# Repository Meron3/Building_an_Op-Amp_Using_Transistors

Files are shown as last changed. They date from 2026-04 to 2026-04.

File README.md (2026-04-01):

# トランジスタで作るスピーカーアンプ

トランジスタ16石で作るスピーカーアンプのkicadプロジェクトです。

kicad9.0以降で開くことができます。

トグルスイッチのフットプリントは、nosuz様のkicad-libをインポートして使用しています。
https://github.com/nosuz/kicad-lib

# 回路図

circuit

# Overview

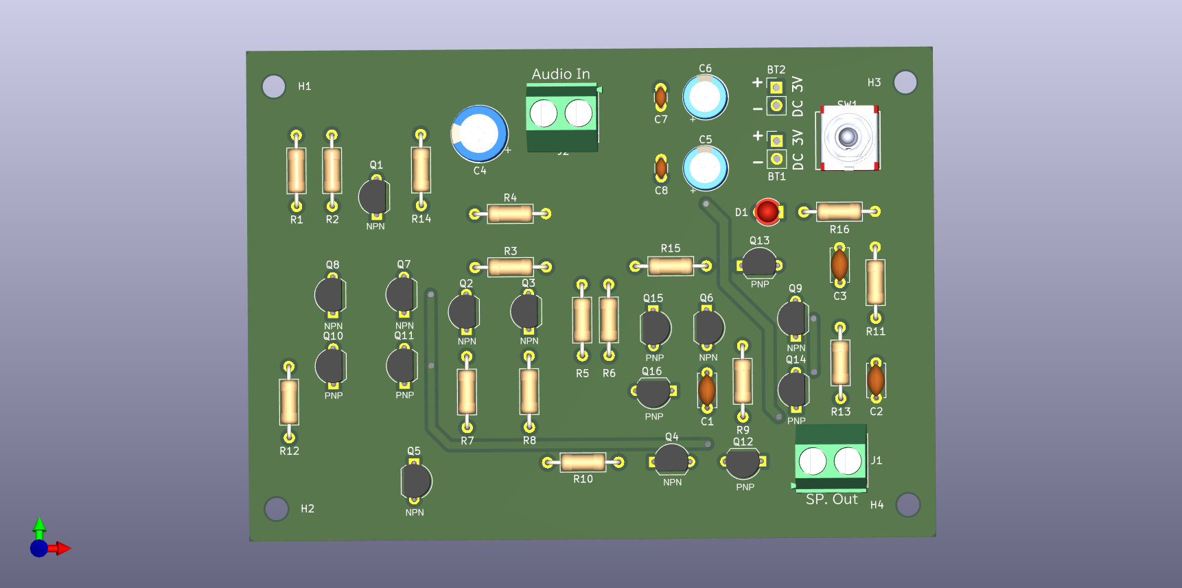
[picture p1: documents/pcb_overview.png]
overview


# Building an Op-Amp Using Transistors

This is a KiCad project for a speaker amplifier using 16 transistors.

It can be opened with KiCad 9.0 or later.

The toggle switch footprint uses KiCad-lib imported by nosuz.
https://github.com/nosuz/kicad-lib

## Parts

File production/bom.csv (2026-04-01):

Designator | Footprint | Quantity | Value | LCSC Part #
BT1, BT2 | PinHeader_1x02_P2.54mm_Vertical | 2 | 3V
C1 | C_Disc_D4.7mm_W2.5mm_P5.00mm | 1 | 220p
C2 | C_Disc_D4.7mm_W2.5mm_P5.00mm | 1 | 2200p
C3 | C_Disc_D4.7mm_W2.5mm_P5.00mm | 1 | 0.047u
C4 | CP_Radial_D8.0mm_P3.50mm | 1 | 10u
C5, C6 | CP_Radial_D6.3mm_P2.50mm | 2 | 220u
C7, C8 | C_Disc_D3.0mm_W1.6mm_P2.50mm | 2 | 0.1u
D1 | LED_D3.0mm | 1 | LED
J1, J2 | TerminalBlock_bornier-2_P5.08mm | 2 | Screw_Terminal_01x02
Q1, Q2, Q3, Q4, Q5, Q6, Q7, Q8, Q9 | TO-92_Inline_Wide | 9 | 2SC1815
Q10, Q11, Q12, Q13, Q14, Q15, Q16 | TO-92_Inline_Wide | 7 | 2SA1015
R1 | R_Axial_DIN0207_L6.3mm_D2.5mm_P10.16mm_Horizontal | 1 | 6.8k
R10, R15 | R_Axial_DIN0207_L6.3mm_D2.5mm_P10.16mm_Horizontal | 2 | 360
R11 | R_Axial_DIN0207_L6.3mm_D2.5mm_P10.16mm_Horizontal | 1 | 180
R12, R4 | R_Axial_DIN0207_L6.3mm_D2.5mm_P10.16mm_Horizontal | 2 | 33k
R13 | R_Axial_DIN0207_L6.3mm_D2.5mm_P10.16mm_Horizontal | 1 | 33
R14 | R_Axial_DIN0207_L6.3mm_D2.5mm_P10.16mm_Horizontal | 1 | 10k
R16, R2 | R_Axial_DIN0207_L6.3mm_D2.5mm_P10.16mm_Horizontal | 2 | 1k
R3 | R_Axial_DIN0207_L6.3mm_D2.5mm_P10.16mm_Horizontal | 1 | 7.5k
R5, R6 | R_Axial_DIN0207_L6.3mm_D2.5mm_P10.16mm_Horizontal | 2 | 2k
R7 | R_Axial_DIN0207_L6.3mm_D2.5mm_P10.16mm_Horizontal | 1 | 1.2k
R8, R9 | R_Axial_DIN0207_L6.3mm_D2.5mm_P10.16mm_Horizontal | 2 | 470
SW1 | 2MD1-T2-B4-M2-Q-N | 1 | SW_DPDT_x2

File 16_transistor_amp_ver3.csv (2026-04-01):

Reference | Qty | Value | Footprint | Datasheet | DNP | Exclude from BOM | Exclude from Board
C1 | 1 | 220p | Capacitor_THT:C_Disc_D4.7mm_W2.5mm_P5.00mm | https://akizukidenshi.com/catalog/g/g108127/
C2 | 1 | 2200p | Capacitor_THT:C_Disc_D4.7mm_W2.5mm_P5.00mm | https://akizukidenshi.com/catalog/g/g108134/
C3 | 1 | 0.047u | Capacitor_THT:C_Disc_D4.7mm_W2.5mm_P5.00mm | https://akizukidenshi.com/catalog/g/g108142/
C7,C8 | 2 | 0.1u | Capacitor_THT:C_Disc_D3.0mm_W1.6mm_P2.50mm | https://akizukidenshi.com/catalog/g/g113582/
C4 | 1 | 10u | Capacitor_THT:CP_Radial_D8.0mm_P3.50mm | https://akizukidenshi.com/catalog/g/g104638/
C5,C6 | 2 | 220u | Capacitor_THT:CP_Radial_D6.3mm_P2.50mm | https://akizukidenshi.com/catalog/g/g110272/
BT1,BT2 | 2 | 3V | Connector_PinHeader_2.54mm:PinHeader_1x02_P2.54mm_Vertical | https://akizukidenshi.com/catalog/g/g101306/
R13 | 1 | 33 | Resistor_THT:R_Axial_DIN0207_L6.3mm_D2.5mm_P10.16mm_Horizontal | https://akizukidenshi.com/catalog/g/g103941/
R11 | 1 | 180 | Resistor_THT:R_Axial_DIN0207_L6.3mm_D2.5mm_P10.16mm_Horizontal | https://akizukidenshi.com/catalog/g/g125181/
R10,R15 | 2 | 360 | Resistor_THT:R_Axial_DIN0207_L6.3mm_D2.5mm_P10.16mm_Horizontal | https://www.marutsu.co.jp/pc/i/1186/
R8,R9 | 2 | 470 | Resistor_THT:R_Axial_DIN0207_L6.3mm_D2.5mm_P10.16mm_Horizontal | https://akizukidenshi.com/catalog/g/g125471/
R2,R16 | 2 | 1k | Resistor_THT:R_Axial_DIN0207_L6.3mm_D2.5mm_P10.16mm_Horizontal | https://akizukidenshi.com/catalog/g/g125102/
R7 | 1 | 1.2k | Resistor_THT:R_Axial_DIN0207_L6.3mm_D2.5mm_P10.16mm_Horizontal | https://akizukidenshi.com/catalog/g/g125122/
R5,R6 | 2 | 2k | Resistor_THT:R_Axial_DIN0207_L6.3mm_D2.5mm_P10.16mm_Horizontal | https://akizukidenshi.com/catalog/g/g125202/
R1 | 1 | 6.8k | Resistor_THT:R_Axial_DIN0207_L6.3mm_D2.5mm_P10.16mm_Horizontal | https://akizukidenshi.com/catalog/g/g125682/
R3 | 1 | 7.5k | Resistor_THT:R_Axial_DIN0207_L6.3mm_D2.5mm_P10.16mm_Horizontal | https://akizukidenshi.com/catalog/g/g125752/
R14 | 1 | 10k | Resistor_THT:R_Axial_DIN0207_L6.3mm_D2.5mm_P10.16mm_Horizontal | https://akizukidenshi.com/catalog/g/g125103/
R4,R12 | 2 | 33k | Resistor_THT:R_Axial_DIN0207_L6.3mm_D2.5mm_P10.16mm_Horizontal | https://akizukidenshi.com/catalog/g/g125333/
Q10,Q11,Q12,Q13,Q14,Q15,Q16 | 7 | 2SA1015 | Package_TO_SOT_THT:TO-92_Inline_Wide | https://akizukidenshi.com/catalog/g/g106735/
Q1,Q2,Q3,Q4,Q5,Q6,Q7,Q8,Q9 | 9 | 2SC1815 | Package_TO_SOT_THT:TO-92_Inline_Wide | https://akizukidenshi.com/catalog/g/g106478/
D1 | 1 | LED | LED_THT:LED_D3.0mm | ~
H1,H2,H3,H4 | 4 | MountingHole | MountingHole:MountingHole_3.2mm_M3 | ~ |  |  | J2" | 2 | Screw_Terminal_01x02 | TerminalBlock:TerminalBlock_bornier-2_P5.08mm | https://akizukidenshi.com/catalog/g/g101306/
SW1 | 1 | SW_DPDT_x2 | 0my_project:2MD1-T2-B4-M2-Q-N | https://akizukidenshi.com/catalog/g/g100301/

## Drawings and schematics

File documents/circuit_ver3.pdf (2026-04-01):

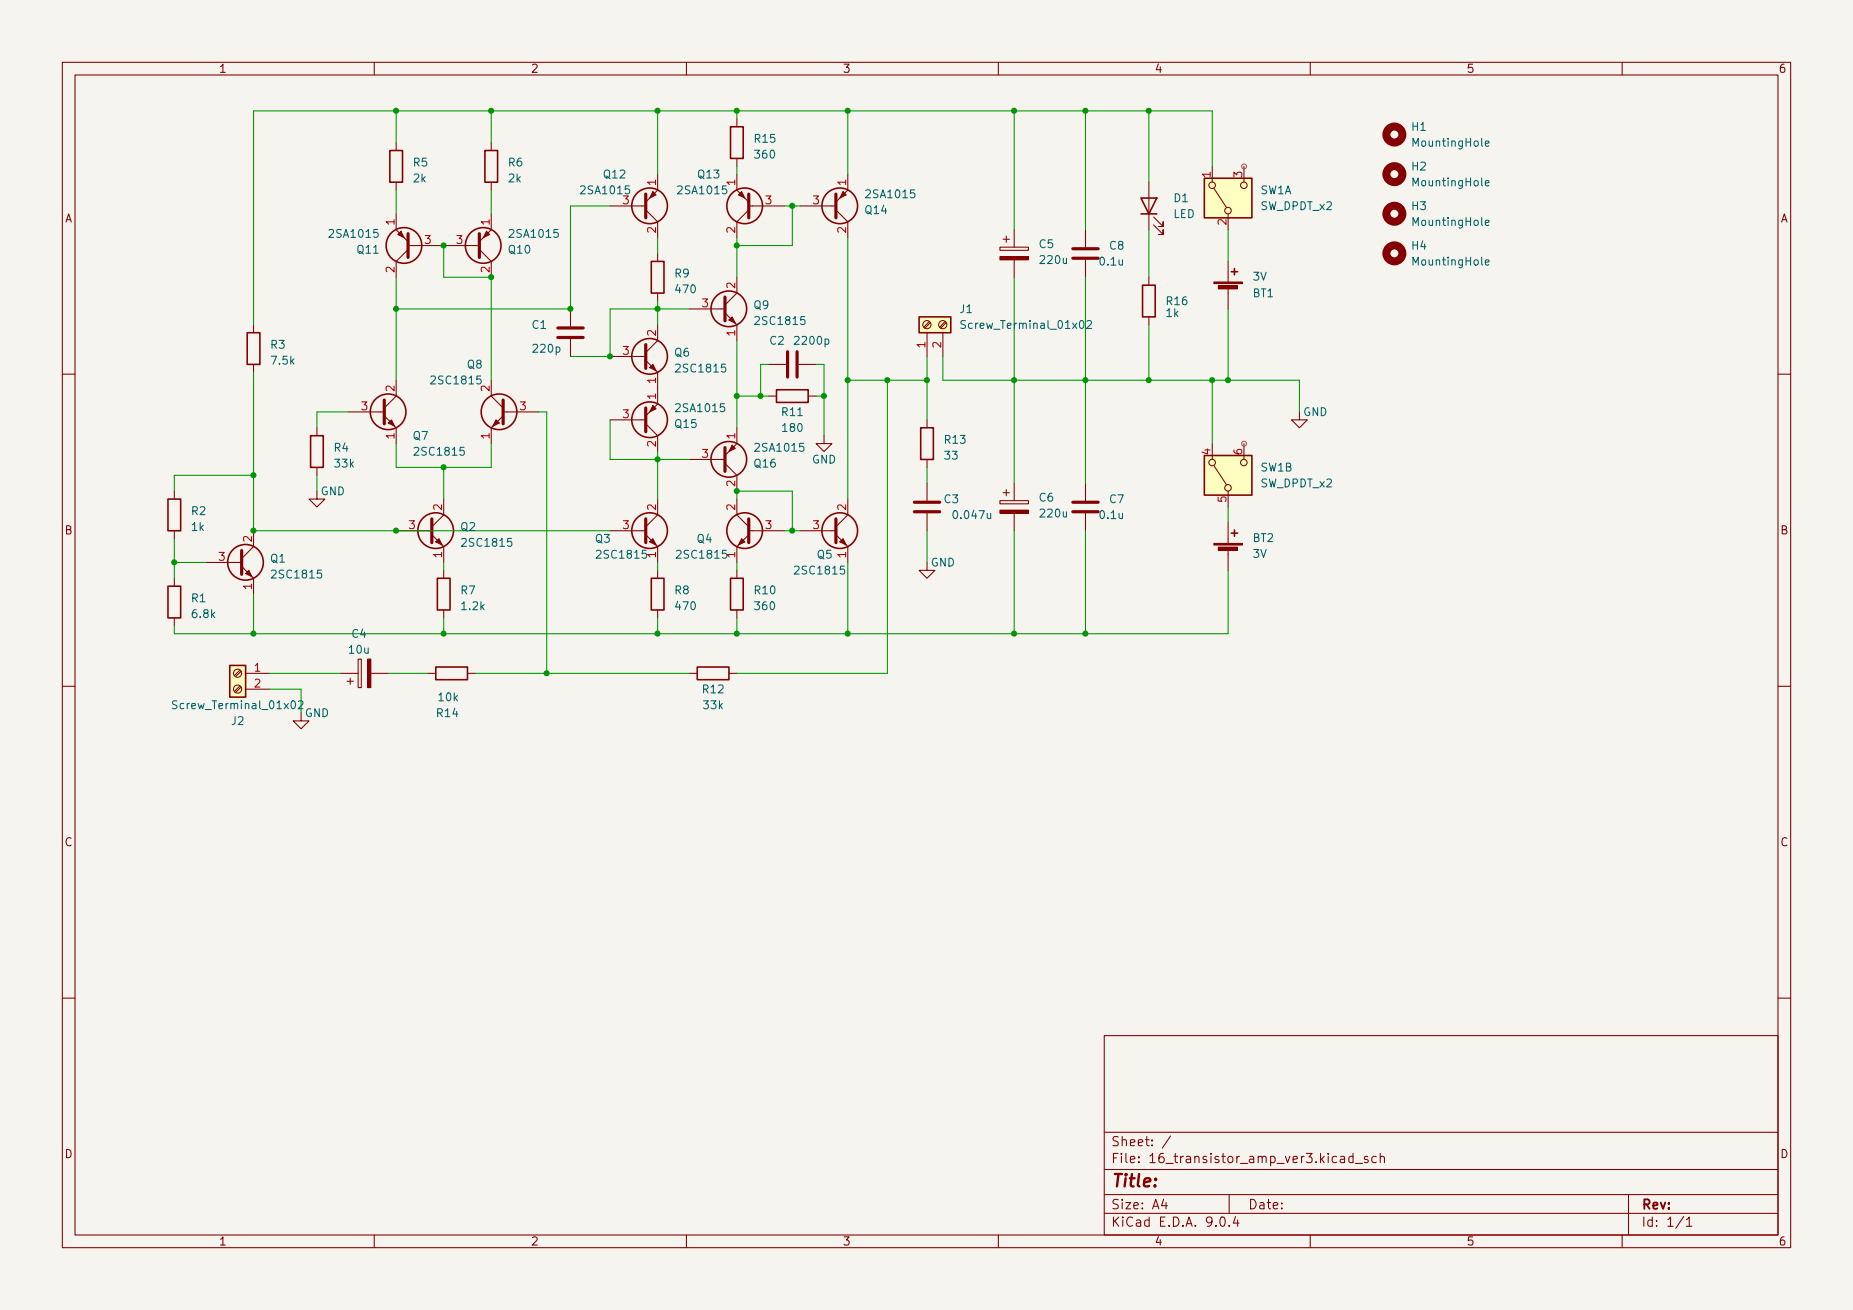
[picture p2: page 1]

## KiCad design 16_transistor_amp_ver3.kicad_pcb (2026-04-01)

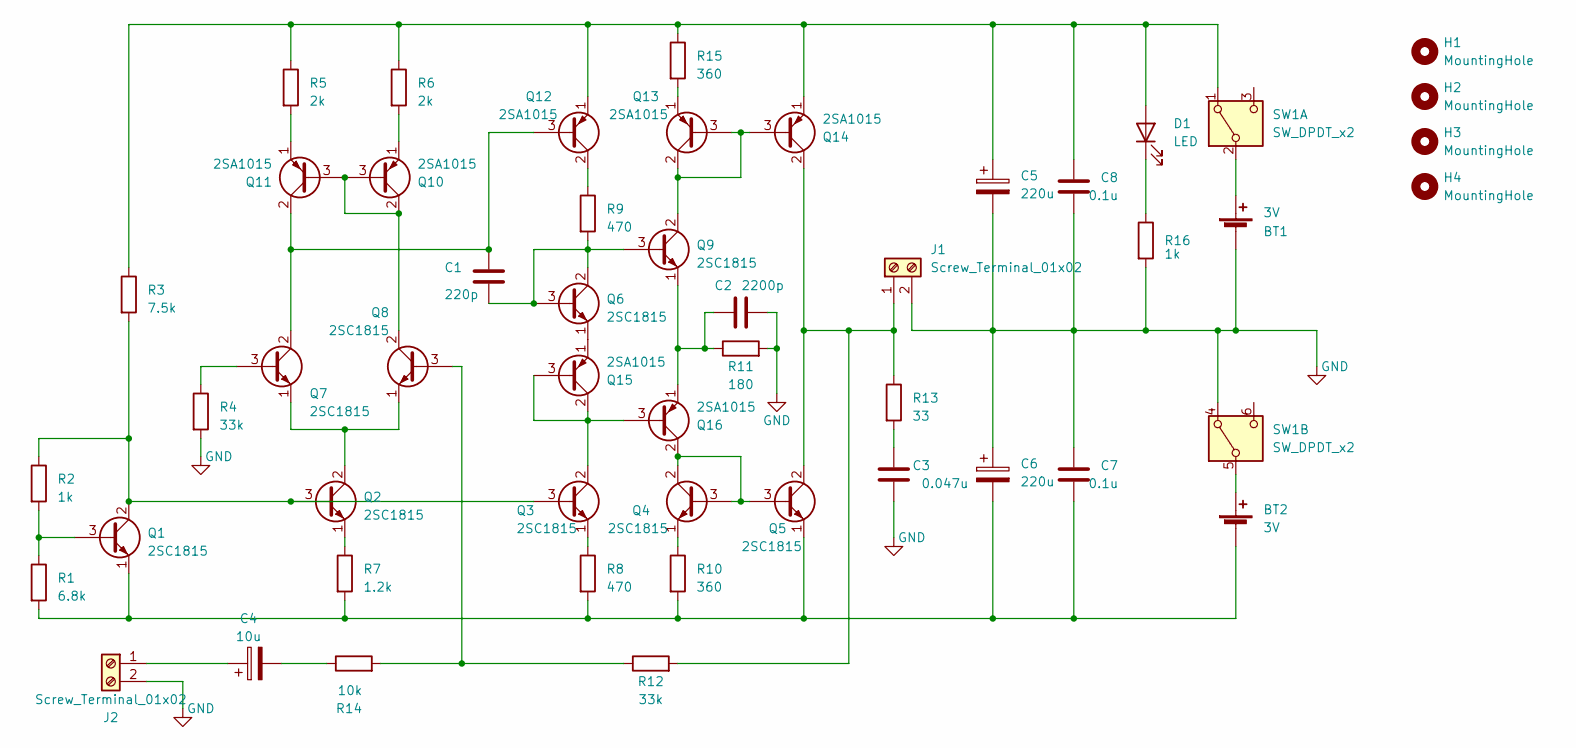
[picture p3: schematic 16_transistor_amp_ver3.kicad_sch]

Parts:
BT1, BT2: 3V; PinHeader_1x02_P2.54mm_Vertical
C1: 220p; C_Disc_D4.7mm_W2.5mm_P5.00mm
C2: 2200p; C_Disc_D4.7mm_W2.5mm_P5.00mm
C3: 0.047u; C_Disc_D4.7mm_W2.5mm_P5.00mm
C4: 10u; CP_Radial_D8.0mm_P3.50mm
C5, C6: 220u; CP_Radial_D6.3mm_P2.50mm
C7, C8: 0.1u; C_Disc_D3.0mm_W1.6mm_P2.50mm
D1: LED; LED_D3.0mm
H1, H2, H3, H4: MountingHole; MountingHole_3.2mm_M3
J1, J2: Screw_Terminal_01x02; TerminalBlock_bornier-2_P5.08mm
Q1, Q2, Q3, Q4, Q5, Q6, Q7, Q8, Q9: 2SC1815; TO-92_Inline_Wide
Q10, Q11, Q12, Q13, Q14, Q15, Q16: 2SA1015; TO-92_Inline_Wide
R1: 6.8k; R_Axial_DIN0207_L6.3mm_D2.5mm_P10.16mm_Horizontal
R2, R16: 1k; R_Axial_DIN0207_L6.3mm_D2.5mm_P10.16mm_Horizontal
R3: 7.5k; R_Axial_DIN0207_L6.3mm_D2.5mm_P10.16mm_Horizontal
R4, R12: 33k; R_Axial_DIN0207_L6.3mm_D2.5mm_P10.16mm_Horizontal
R5, R6: 2k; R_Axial_DIN0207_L6.3mm_D2.5mm_P10.16mm_Horizontal
R7: 1.2k; R_Axial_DIN0207_L6.3mm_D2.5mm_P10.16mm_Horizontal
R8, R9: 470; R_Axial_DIN0207_L6.3mm_D2.5mm_P10.16mm_Horizontal
R10, R15: 360; R_Axial_DIN0207_L6.3mm_D2.5mm_P10.16mm_Horizontal
R11: 180; R_Axial_DIN0207_L6.3mm_D2.5mm_P10.16mm_Horizontal
R13: 33; R_Axial_DIN0207_L6.3mm_D2.5mm_P10.16mm_Horizontal
R14: 10k; R_Axial_DIN0207_L6.3mm_D2.5mm_P10.16mm_Horizontal
SW1: SW_DPDT_x2; 2MD1-T2-B4-M2-Q-N

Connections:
GND: BT1.2 (-), C2.1, C3.2, C5.2, C6.1, C7.2, C8.1, J1.2, J2.2, R4.2, R11.2, R16.2, SW1.4 (A)
unnamed: BT1.1 (+), SW1.2 (B)
unnamed: BT2.1 (+), SW1.5 (B)
unnamed: BT2.2 (-), C6.2, C7.1, Q1.1 (E), Q5.1 (E), R1.2, R7.2, R8.2, R10.2
unnamed: C3.1, R13.2
unnamed: C4.2, R14.1
unnamed: C5.1, C8.2, D1.2 (A), Q12.1 (E), Q14.1 (E), R3.1, R5.1, R6.1, R15.1, SW1.1 (A)
unnamed: D1.1 (K), R16.1
unnamed: J1.1, Q5.2 (C), Q14.2 (C), R12.2, R13.1
unnamed: C4.1, J2.1
unnamed: Q1.3 (B), R1.1, R2.2
unnamed: Q1.2 (C), Q2.3 (B), Q3.3 (B), R2.1, R3.2
unnamed: Q2.2 (C), Q7.1 (E), Q8.1 (E)
unnamed: Q2.1 (E), R7.1
unnamed: Q3.1 (E), R8.1
unnamed: Q4.1 (E), R10.1
unnamed: C1.2, Q6.2 (C), Q6.3 (B), Q9.3 (B), R9.2
unnamed: Q7.3 (B), R4.1
unnamed: Q8.3 (B), R12.1, R14.2
unnamed: Q8.2 (C), Q10.2 (C), Q10.3 (B), Q11.3 (B)
unnamed: Q10.1 (E), R6.2
unnamed: C1.1, Q7.2 (C), Q11.2 (C), Q12.3 (B)
unnamed: Q11.1 (E), R5.2
unnamed: Q12.2 (C), R9.1
unnamed: Q9.2 (C), Q13.2 (C), Q13.3 (B), Q14.3 (B)
unnamed: Q13.1 (E), R15.2
unnamed: Q3.2 (C), Q15.2 (C), Q15.3 (B), Q16.3 (B)
unnamed: Q6.1 (E), Q15.1 (E)
unnamed: Q4.2 (C), Q4.3 (B), Q5.3 (B), Q16.2 (C)
unnamed: C2.2, Q9.1 (E), Q16.1 (E), R11.1

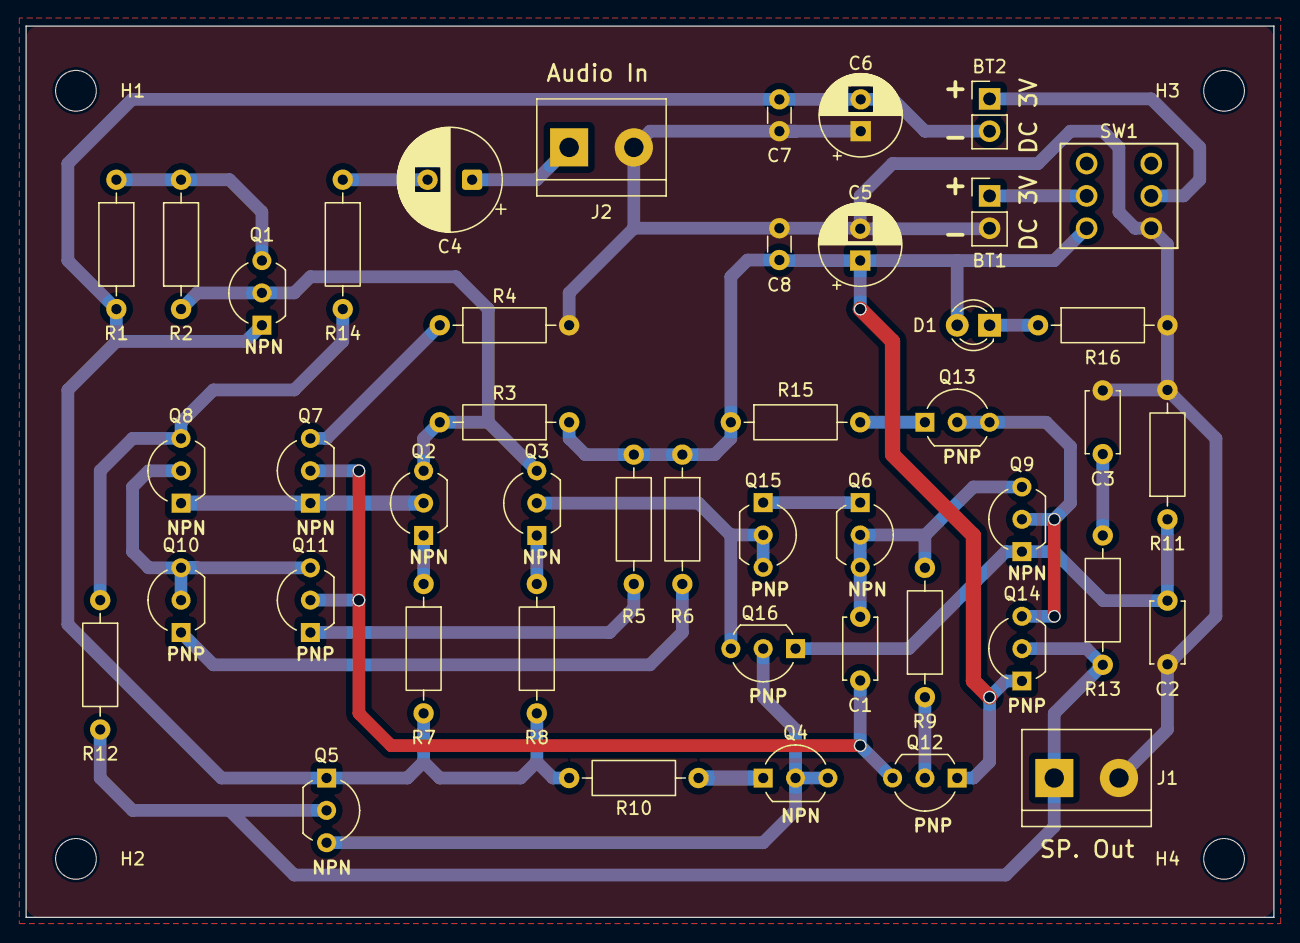
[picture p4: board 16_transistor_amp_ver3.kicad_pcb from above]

Board: 2 copper layers, 98.0 x 70.0 mm, 50 parts (0 on the bottom side), 30 nets.
